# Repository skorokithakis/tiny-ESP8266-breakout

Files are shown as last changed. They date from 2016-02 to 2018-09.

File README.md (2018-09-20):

# Tiny ESP8266 Breakout Board

This is a tiny ESP8266 breakout board. I made it because the small breakouts I
bought took up the entire breadboard and didn't include basic pullup/pulldown
resistors.

## Tinier PCB

This repository includes a branch with [an even tinier
version](https://github.com/skorokithakis/tiny-ESP8266-breakout/tree/tinier)
that is smaller than an ESP8266 12E. It's the size of the 12E minus the antenna,
and it includes the voltage regulator and all the capacitors and resistors
the ESP8266 needs to boot, but it doesn't include through-hole connectors (so
you will have to solder wires directly onto the ESP8266 contacts).

It's for when you really really need as much space as you can. Fabricate it
at 0.4mm thickness and enjoy.

## Ready-made PCB

If you just want to buy the PCB directly, here's [a paneled v1.4
version from Dirty
PCBs](http://dirtypcbs.com/view.php?share=17018&accesskey=47b880c9e762ffa555ab1070dc1a2dde),
which includes 40 breakouts for $14. Note that the boards come without
components, and you'll have to solder them yourself. You'll need:

* [0805 SMD 10k Ohm
  resistors](https://www.aliexpress.com/item/0805-SMD-Resistor-5-10K-ohm-5000pcs-lot/32307395708.html)
* [0805 SMD 10 uF
  capacitors](https://www.aliexpress.com/item/Free-shipping-0805-SMD-capacitor-10uf-16V-106K-100PCS/32376052582.html)
* [SPX3819M5-L-3-3 TR 3.3V SMD
  LDO](https://www.aliexpress.com/item/10PCS-SPX3819M5-SPX3819M5-3-3-SPX3819M5-L-3-3-TR-SOT-23-5/32522603067.html)
* [Male pin headers
  (optional)](https://www.aliexpress.com/item/Free-Shipping-10pcs-40-Pin-1x40-Single-Row-Male-2-54-Breakable-Pin-Header-Connector-Strip/32416951874.html)

If any of the links above aren't working, just search your favorite site for the
components or visit your local electronics shop, they should have all of these.

You can use these ESP8266 versions with this PCB:

* ESP-07
* ESP-12
* ESP-12E
* ESP-12Q
* ESP-12F
* ESP-14

## License

Use the board however you want, it's under the BSD license, here's what it looks
like:

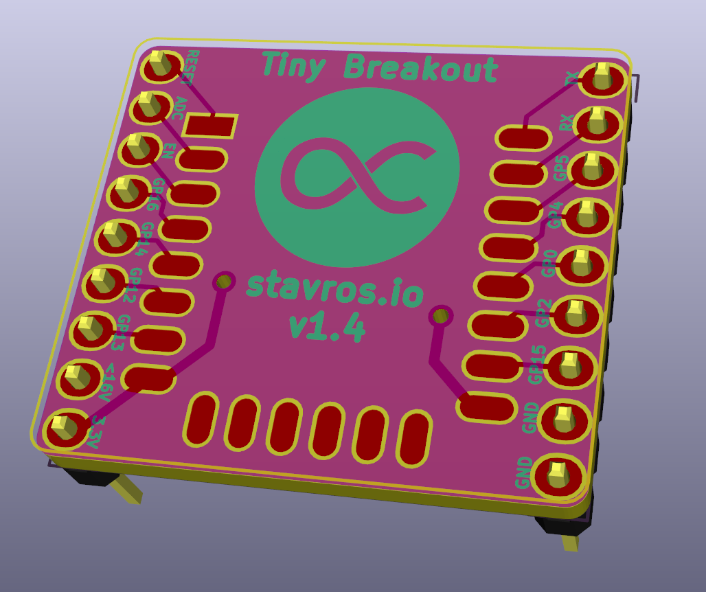
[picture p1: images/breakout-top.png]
Front

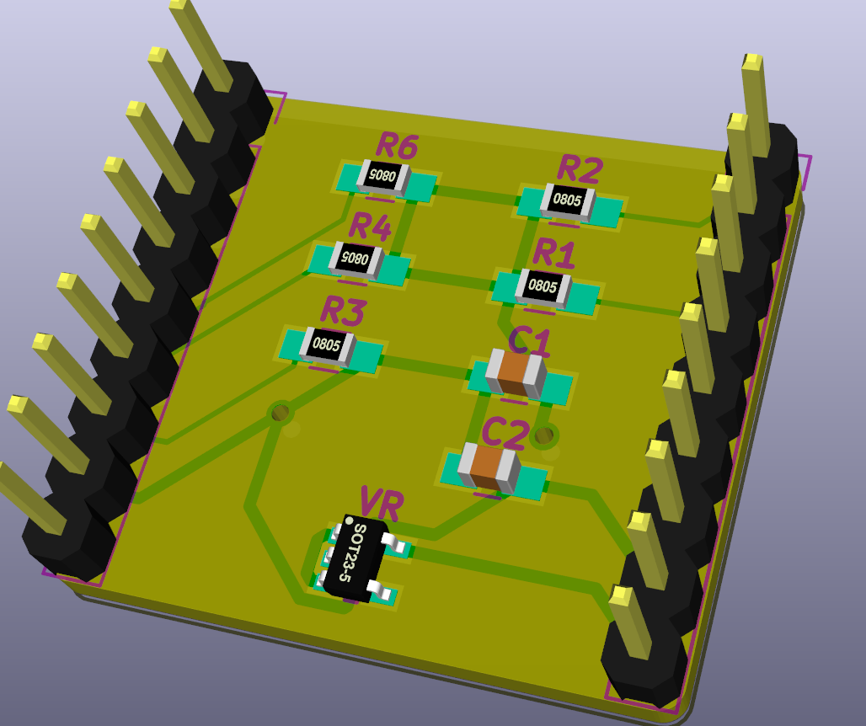
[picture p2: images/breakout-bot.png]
Back

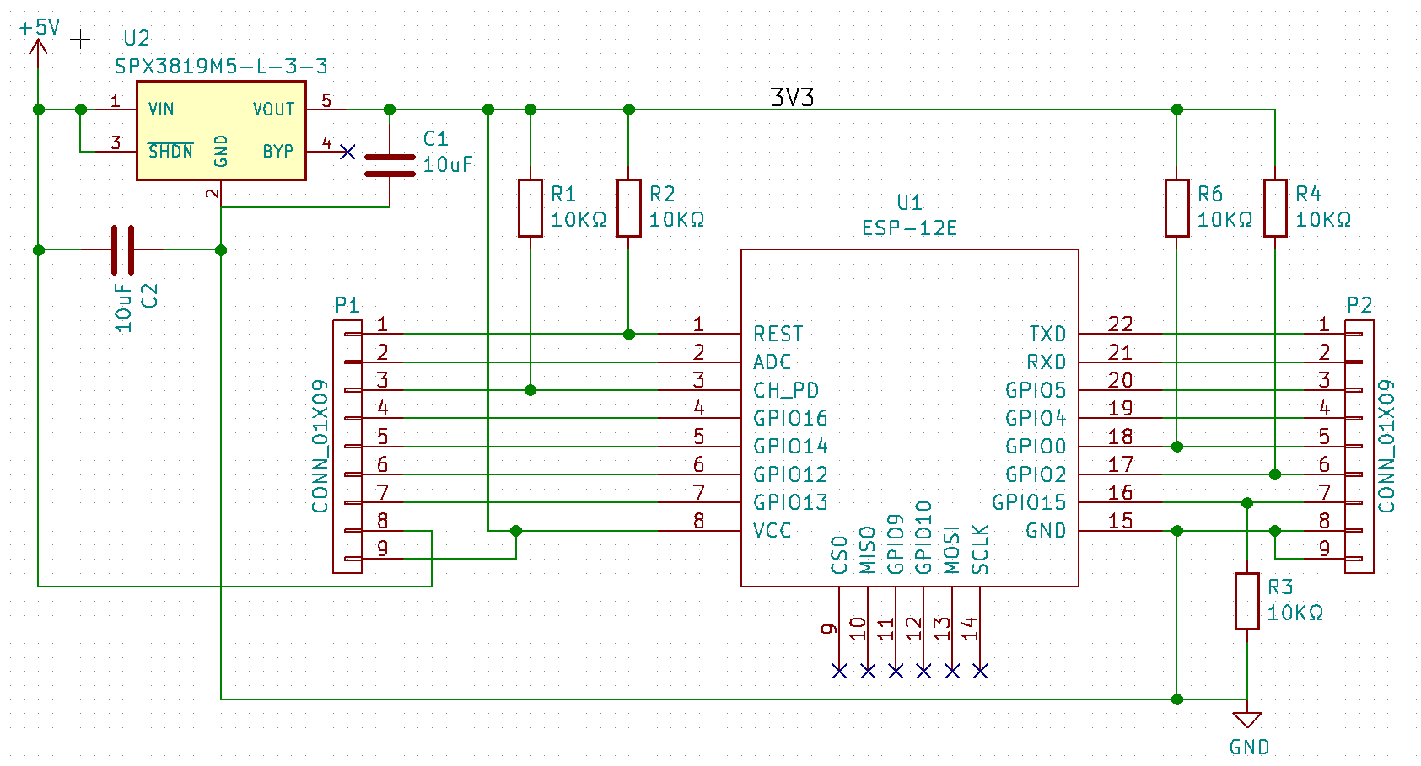
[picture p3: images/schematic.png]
Schematic


The files are standard KiCad files, go nuts.

Stavros

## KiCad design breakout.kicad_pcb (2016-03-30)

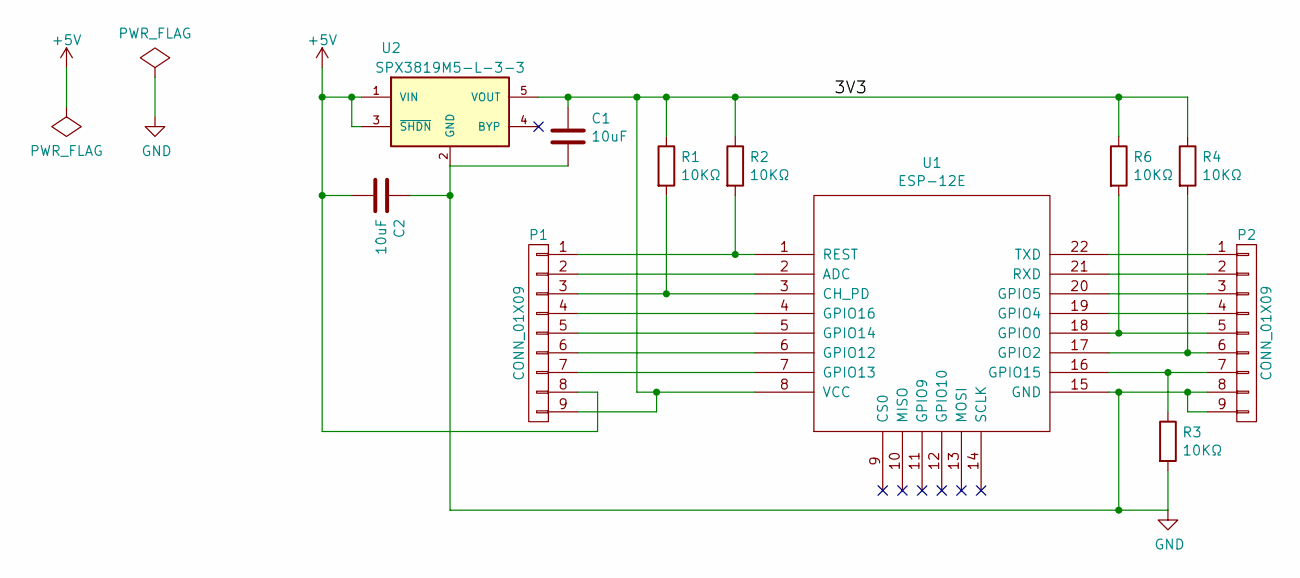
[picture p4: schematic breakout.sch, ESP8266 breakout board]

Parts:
C1, C2: 10uF; C_0805_HandSoldering
P1, P2: CONN_01X09; Pin_Header_Straight_1x09
R1, R2, R3, R4, R6: 10KΩ; R_0805_HandSoldering
U1: ESP-12E
U2: SPX3819M5-L-3-3; SOT-23-5

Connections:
+12V: C2.2, P1.8, U2.1 (VIN), U2.3 (~SHDN~)
/3V3: C1.1, P1.9, R1.1, R2.1, R4.1, R6.1, U1.8 (VCC), U2.5 (VOUT)
GND: C1.2, C2.1, P2.8, P2.9, R3.2, U1.15 (GND), U2.2 (GND)
unnamed: P1.1, R2.2, U1.1 (REST)
unnamed: P1.2, U1.2 (ADC)
unnamed: P1.3, R1.2, U1.3 (CH_PD)
unnamed: P1.4, U1.4 (GPIO16)
unnamed: P1.5, U1.5 (GPIO14)
unnamed: P1.6, U1.6 (GPIO12)
unnamed: P1.7, U1.7 (GPIO13)
unnamed: P2.1, U1.22 (TXD)
unnamed: P2.2, U1.21 (RXD)
unnamed: P2.3, U1.20 (GPIO5)
unnamed: P2.4, U1.19 (GPIO4)
unnamed: P2.5, R6.2, U1.18 (GPIO0)
unnamed: P2.6, R4.2, U1.17 (GPIO2)
unnamed: P2.7, R3.1, U1.16 (GPIO15)

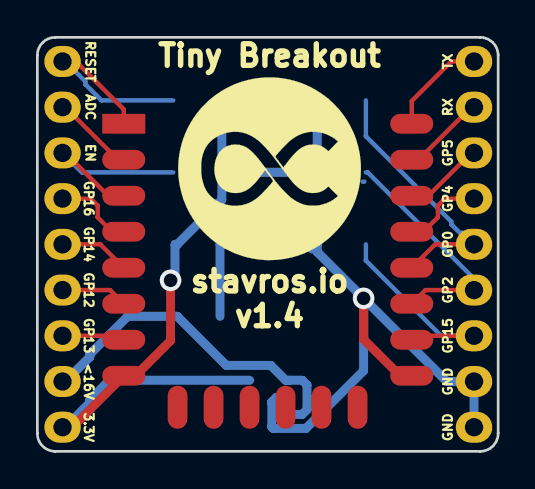
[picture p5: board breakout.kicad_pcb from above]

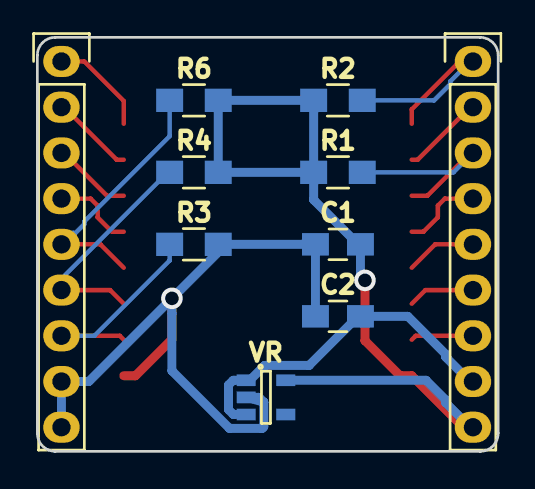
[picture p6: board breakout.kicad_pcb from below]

Board: 2 copper layers, 25.6 x 23.0 mm, 11 parts (10 on the bottom side), 17 nets.

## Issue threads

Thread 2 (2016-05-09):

Required components

mcauser, 2016-05-09:
You can find the required components on http://aliexpress.com significantly cheaper than on ebay.

erod998, 2018-05-21:
The schematic says 10uf caps, but the links say 22uf. I'm pretty sure its 10uf as another breakout I am using is 10uf.

skorokithakis, 2018-05-21:
You are correct, changed! The links have been fixed for a while, so I'm closing this.

Closed 2018-05-21.

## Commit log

2015-12-30 Initial commit.
    [breakout.kicad_pcb, breakout.sch]
2015-12-30 Add pullup resistor to GPIO2.
    [breakout.kicad_pcb, breakout.sch]
2015-12-30 Clean up, enlarge vias.
    [breakout.kicad_pcb]
2015-12-30 Increase power via size.
    [breakout.kicad_pcb]
2015-12-30 Update Gerber export values.
    [breakout.kicad_pcb]
2015-12-31 Make vias a bit prettier.
    [breakout.kicad_pcb]
2016-01-02 Update images.
    [breakout.sch]
2016-01-05 Make it more Web 2.0.
    [breakout.kicad_pcb]
2016-01-06 Add pin.
    [breakout.kicad_pcb, breakout.sch]
2016-01-06 Rewire everything.
    [breakout.kicad_pcb, breakout.sch]
2016-01-10 Remove measurements.
    [breakout.kicad_pcb]
2016-01-12 Change to HT7333 regulator.
    [breakout.kicad_pcb, breakout.sch]
2016-01-14 Switch back to the SPX regulator.
    [breakout.kicad_pcb, breakout.sch]
2016-01-29 Make PCB a bit smaller.
    [breakout.kicad_pcb, breakout.sch]
2016-02-17 Update link with 1.4 PCB.
2016-03-30 Remove erroneous USB_OTG component.
    [breakout.kicad_pcb, breakout.sch]
2016-04-12 Add BOM.
2016-04-14 Change caps to 22uF.
    [breakout.sch]
2018-05-21 Change capacitor link
2018-09-20 Add tinier PCB blurb to the README
